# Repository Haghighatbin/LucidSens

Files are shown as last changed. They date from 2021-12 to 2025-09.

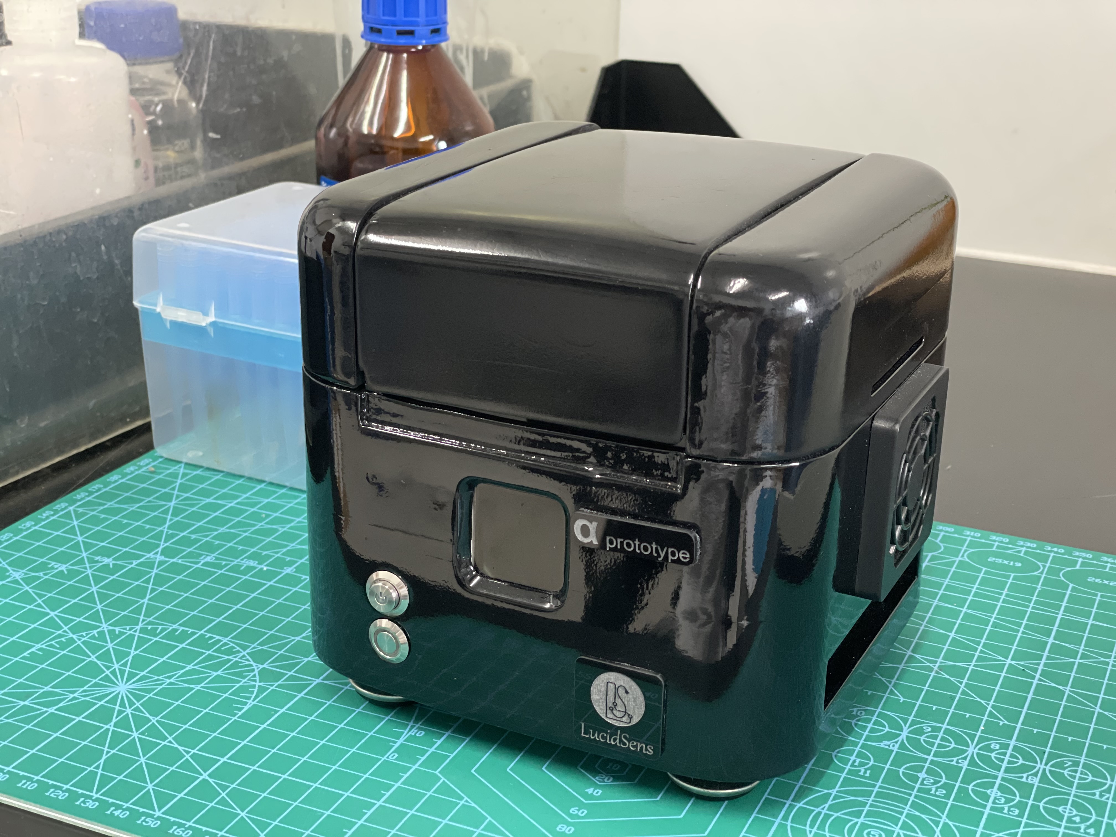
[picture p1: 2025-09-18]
Images/IMG_0355.jpg

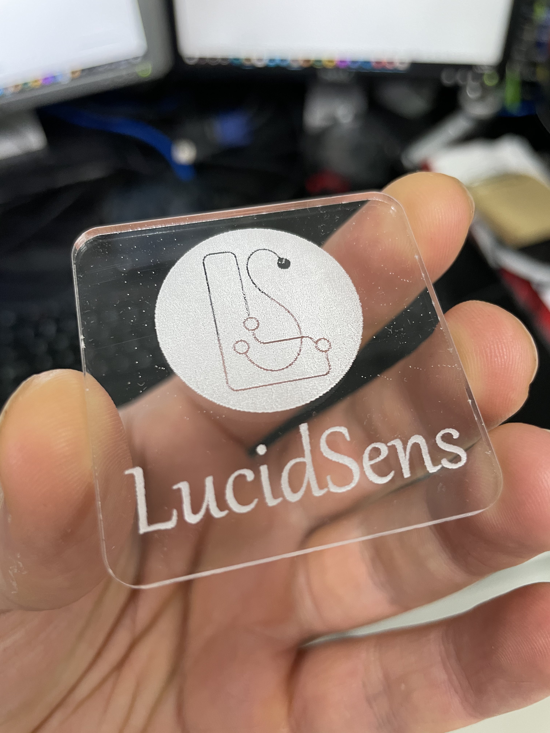
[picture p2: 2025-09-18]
Images/IMG_9384.jpg

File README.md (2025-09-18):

# LucidSens

<b>A device for electrochemiluminescence (ECL)-based measurements</b><br /><br />

<p align='justify'>
  There is a common agreement that the most indicative clinical procedure for rapid and early diagnosis of diseases is to monitor the concentration of specific biomarkers in the patient’s analytical sample at the early stages of the incident using point-of-care (POC) technologies. Among the POC sensing devices, luminescence-based sensing methodologies have been a dominant trend in clinical procedures mostly owing to their tremendously high sensitivity, specificity and rapidity in the analysis of multiplex analytical samples. However, achieving high photosensitivity and versatility to process multiple samples in luminescence-based POC devices commonly come at a cost of compromising the affordability aspect of such sensing devices. <br /><br />To address the gap, <b>LucidSens</b>, a cost-effective luminescence-based POC sensing device is developed for highly sensitive and precise determination of electrochemiluminescence (ECL) and chemiluminescence (CL)-based biological samples. While designed to be portable and cost-efficient, the device provides the versatility of operating in two operational modes: <b>incubation</b> and <b>detection</b> modes. In the incubation mode, the integrity of the process is validated and assured by a PID (proportional, integral, derivative) algorithm with a temperature-sensing feedback loop controlling the implemented Peltier heating/cooling module. In the detection mode, the system is capable of collecting ECL/CL signals of up to 18 analytical samples utilizing an implemented silicon-photomultiplier (SiPM) biased by a miniaturized onboard high-voltage power supply and built-in pseudo-potentiostat modules. The portable architecture of the device as well as remarkable photosensitivity, cost-efficiency and convenient operational instruction may propose the current platform as a versatile analytical template to be adapted for a wide range of ECL/CL-based clinical and bio-analytical determinations.</p><br />
  
Designed and developed by <b><aminhb@tutanota.com></b>

# Firmware
The firmware has been written in Micropython (Loboris port ESP32_LoBo_v3.2.24) based on Espressif ESP32-WROVER-B/I modules with 4MB external SPI flash and 8MB PSRAM.<br />
https://github.com/Haghighatbin/LucidSens/tree/master/Firmware

# Software
Created by: PyQt5 and UI code generator 5.15.4 - sourcefile was written in Python 3.5<br />
https://github.com/Haghighatbin/LucidSens/tree/master/Software   <br />
[Screenshot]
LucidSens_GUI

# PCB Layout and Schematics
https://github.com/Haghighatbin/LucidSens/tree/master/PCB_Schematics_Layouts
LucidSens_2 01v

# CAD files
https://github.com/Haghighatbin/LucidSens/tree/master/CADs

# 3D View
https://user-images.githubusercontent.com/10771949/146338794-2b45d992-ebb1-41cf-bab1-338458c2112e.mp4

# Blueprint 
Blueprint

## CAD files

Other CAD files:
CADs/LinearSlider_0.skp
CADs/LucidSens_01_Blower_REV2.skp
CADs/LucidSens_01_Body_REV2.skp
CADs/LucidSens_01_Body_REV3.skp
CADs/LucidSens_01_Body_REV4.skp
CADs/LucidSens_01_Bracket_REV1.skp
CADs/LucidSens_01_Casquette_REV2.skp
CADs/LucidSens_01_Lid_95.4_REV2.skp
CADs/LucidSens_01_SampleHolder_REV5_51.8.skp
CADs/LucidSens_01_SampleHolder_REV7.skp
CADs/LucidSens_01_TEMPFLOP.skp
CADs/LucidSens_01_Tables.skp
CADs/LucidSens_01_Tables2.skp
CADs/LucidSens_01_Tables2_Interupter.skp
CADs/LucidSens_01_Tables2_SiPM.skp
CADs/LucidSens_beta_BlowerOutlet_BentTube_lefter_twisted_101121.skp
CADs/LucidSens_beta_EJack_TwistedBentBlowerOutlet_MergedSheath_SliderBackHold_301021.skp
CADs/LucidSens_beta_ELever_301021.skp
CADs/LucidSens_beta_ElectrodeJack_SiPMmount_21221.skp
CADs/LucidSens_beta_ElectrodeJack_SiPMmount_301021.skp
CADs/LucidSens_beta_Frontflop_0.skp
CADs/LucidSens_beta_MagneticPogos_301021.skp
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

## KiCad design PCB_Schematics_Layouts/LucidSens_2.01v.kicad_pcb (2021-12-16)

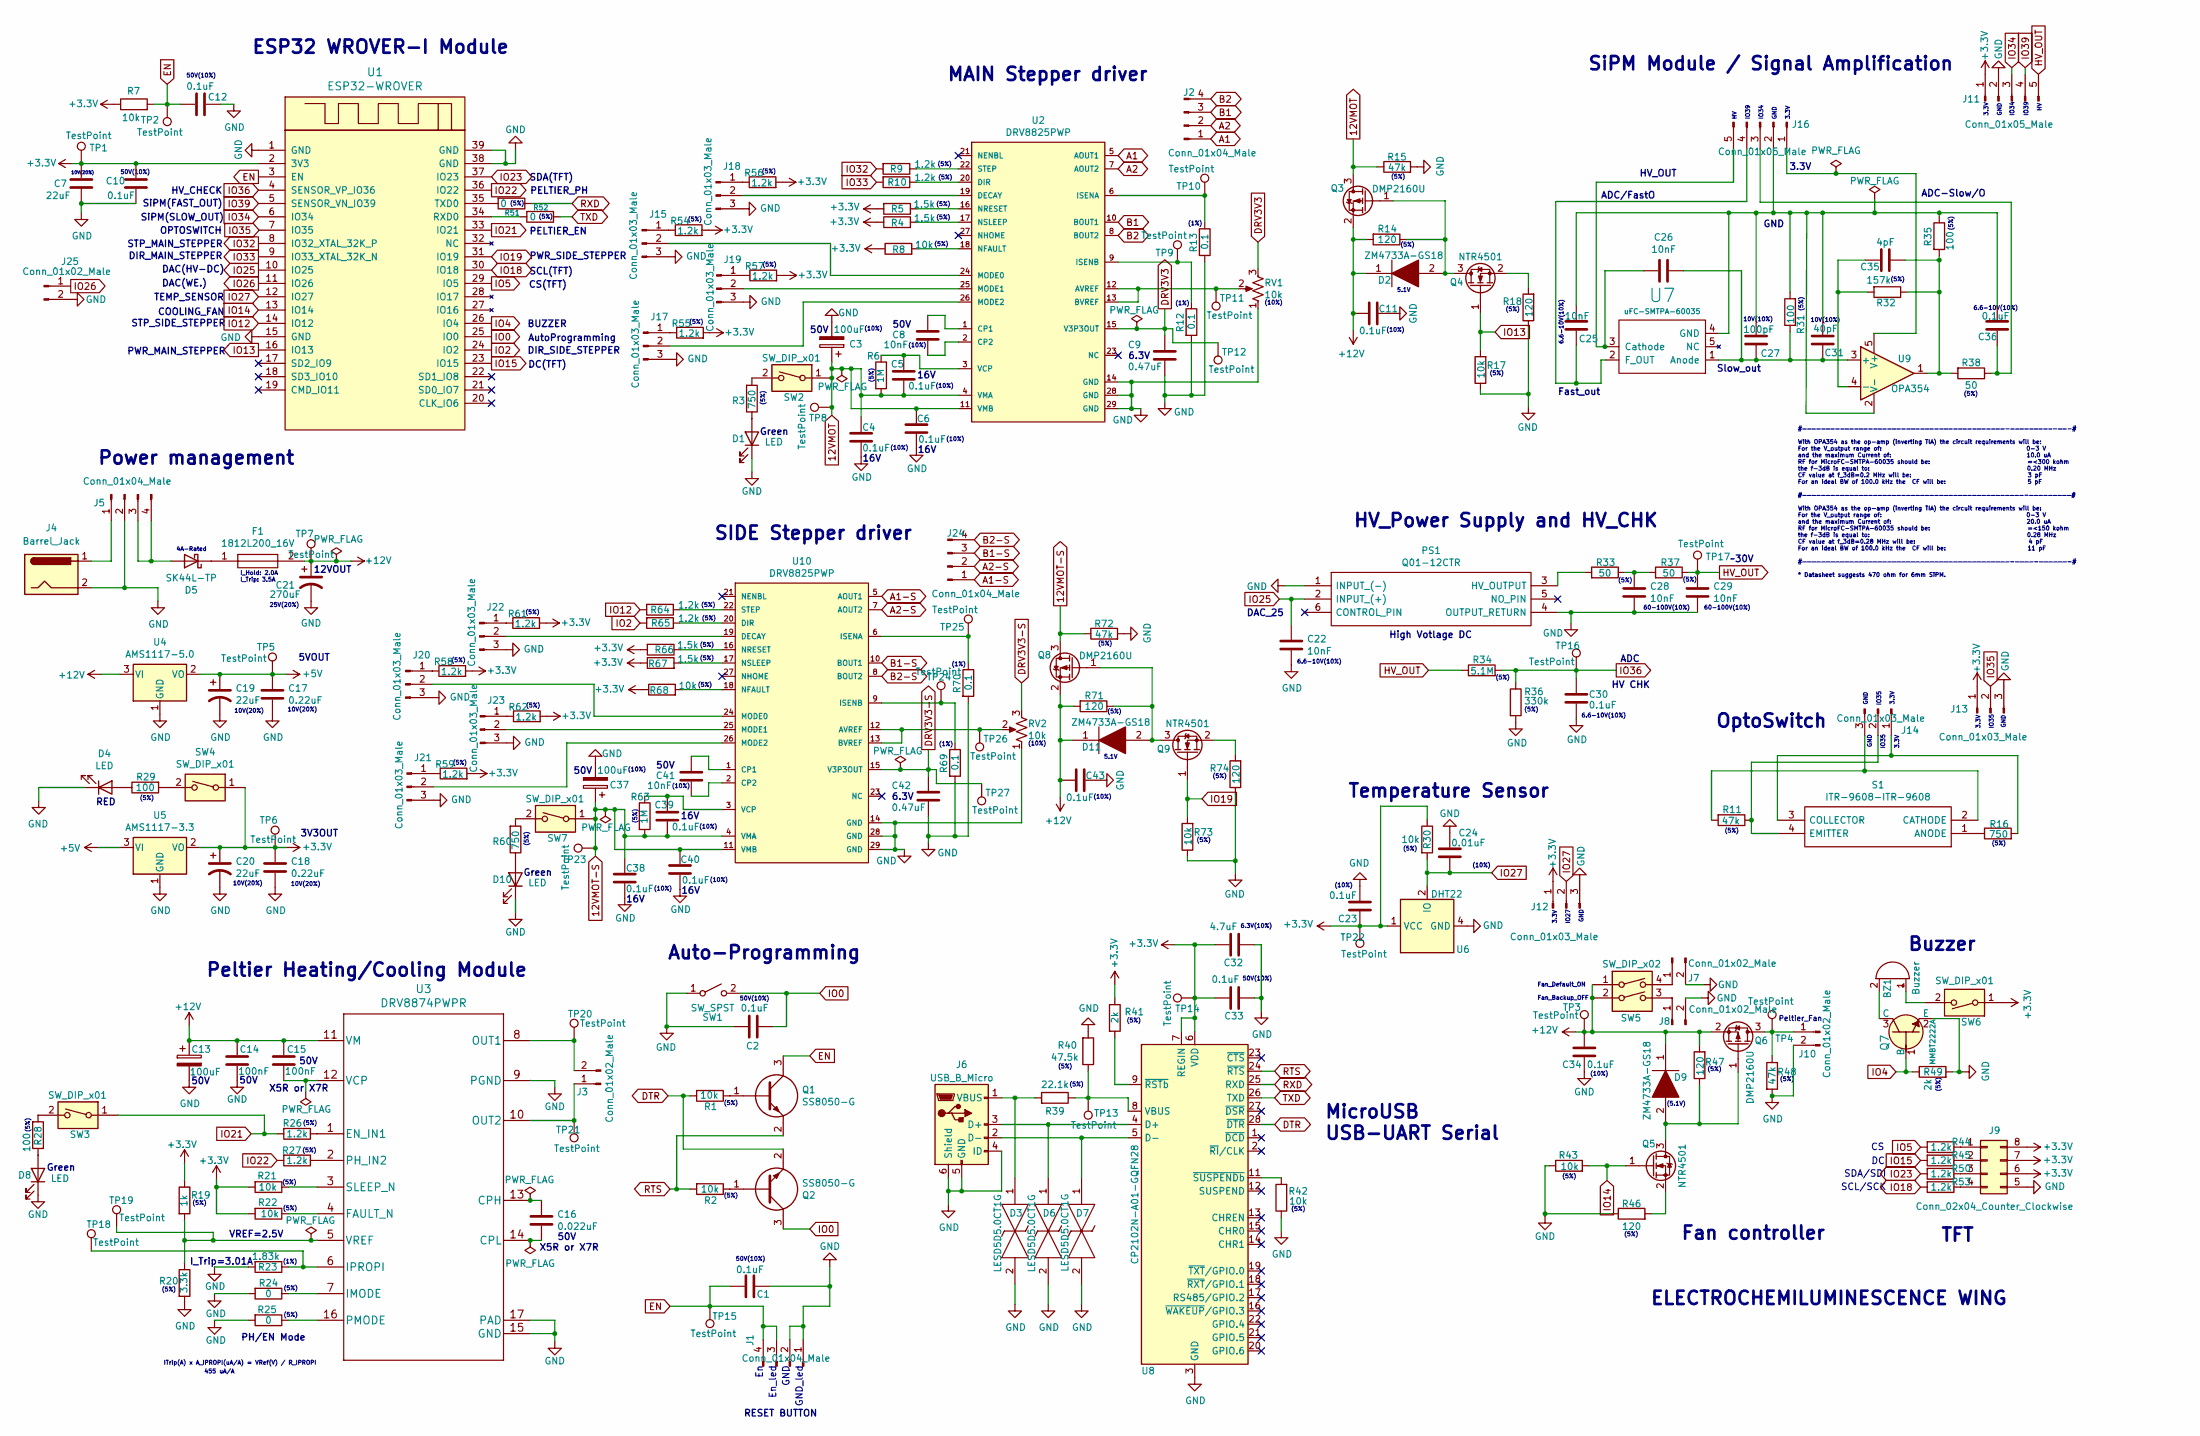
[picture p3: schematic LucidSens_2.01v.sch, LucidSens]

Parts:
BZ1: Buzzer; Buzzer_12x9.5RM7.6
C1, C2, C4, C5, C6, C10, C11, C12, C23, C30, C33, C34, C36, C38, C39, C40, C43: 0.1uF; C_0805_2012Metric_Pad1.18x1.45mm_HandSolder
C3, C13, C37: 100uF; CAPAE660X800N
C7: 22uF; C_0805_2012Metric_Pad1.18x1.45mm_HandSolder
C8, C22, C25, C26, C28, C29, C41: 10nF; C_0805_2012Metric_Pad1.18x1.45mm_HandSolder
C9, C42: 0.47uF; C_0805_2012Metric_Pad1.18x1.45mm_HandSolder
C14, C15: 100nF; C_0805_2012Metric_Pad1.18x1.45mm_HandSolder
C16: 0.022uF; C_0805_2012Metric_Pad1.18x1.45mm_HandSolder
C17, C18: 0.22uF; C_0805_2012Metric_Pad1.18x1.45mm_HandSolder
C19, C20: 22uF; CAPAE530X610N
C21: 270uF; CAPAE830X1050N
C24: 0.01uF; C_0805_2012Metric_Pad1.18x1.45mm_HandSolder
C27: 100pF; C_0805_2012Metric_Pad1.18x1.45mm_HandSolder
C31: 40pF; C_0805_2012Metric_Pad1.18x1.45mm_HandSolder
C32: 4.7uF; C_0805_2012Metric_Pad1.18x1.45mm_HandSolder
C35: 4pF; C_0805_2012Metric_Pad1.18x1.45mm_HandSolder
D1, D4, D8, D10: LED; LED_0805_2012Metric
D2, D9, D11: ZM4733A-GS18; MELF_DO-213AB; Manufacturer_Part_Number ZM4733A-GS18; Mouser Part Number 625-ZM4733A-GS18
D3, D6, D7: LESD5D5.0CT1G; LESD5D50CT1G; Manufacturer_Part_Number LESD5D5.0CT1G
D5: SK44L-TP; D_SMC
F1: 1812L200_16V; FUSC4632X180N; Manufacturer_Part_Number 1812L150/24MR; Mouser Part Number 576-1812L150/24MR
J1, J2, J5, J24: Conn_01x04_Male; PhoenixContact_MSTBVA_2,5_4-G-5,08_1x04_P5.08mm_Vertical
J3: Conn_01x02_Male; TerminalBlock_Phoenix_MKDS-1,5-2-5.08_1x02_P5.08mm_Horizont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
J4: Barrel_Jack; BarrelJack_CUI_PJ-063AH_Horizontal
J6: USB_B_Micro; USB_Micro-B_Molex_47346-0001
J7, J8, J10, J25: Conn_01x02_Male; JST_EH_B2B-EH-A_1x02_P2.50mm_Vertical
J9: Conn_02x04_Counter_Clockwise; JST_PHD_B8B-PHDSS_2x04_P2.00mm_Vertical
J11, J16: Conn_01x05_Male; JST_EH_B5B-EH-A_1x05_P2.50mm_Vertical
J12, J13, J14: Conn_01x03_Male; JST_EH_B3B-EH-A_1x03_P2.50mm_Vertical
J15, J17, J18, J19, J20, J21, J22, J23: Conn_01x03_Male; PinHeader_1x03_P2.54mm_Vertical
PS1: Q01-12CTR; Q0112CTR; Manufacturer_Part_Number Q01-12CTR
Q1, Q2: SS8050-G; SOT95P240X115-3N; Manufacturer_Part_Number SS8050-G; Mouser Part Number 750-SS8050-G
Q3, Q6, Q8: DMP2160U; SOT-23
Q4, Q5, Q9: NTR4501; SOT-23
Q7: MMBT2222A; SOT95P240X120-3N; MPN MMBT2222A-7-F; Digi-Key_PN MMBT2222A-FDICT-ND
R1, R2, R7, R8, R17, R21, R22, R30, R42, R43, R68, R73: 10k; R_0805_2012Metric_Pad1.20x1.40mm_HandSolder
R3, R16, R60: 750; R_0805_2012Metric_Pad1.20x1.40mm_HandSolder
R4, R5, R66, R67: 1.5k; R_0805_2012Metric_Pad1.20x1.40mm_HandSolder
R6, R63: 1M; R_0805_2012Metric_Pad1.20x1.40mm_HandSolder
R9, R10, R26, R27, R44, R45, R50, R53, R54, R55, R56, R57, R58, R59, R61, R62, R64, R65: 1.2k; R_0805_2012Metric_Pad1.20x1.40mm_HandSolder
R11, R15, R48, R72: 47k; R_0805_2012Metric_Pad1.20x1.40mm_HandSolder
R12, R13, R69, R70: 0.1; R_0805_2012Metric_Pad1.20x1.40mm_HandSolder
R14, R18, R46, R47, R71, R74: 120; R_0805_2012Metric_Pad1.20x1.40mm_HandSolder
R19: 1k; R_0805_2012Metric_Pad1.20x1.40mm_HandSolder
R20: 3.3k; R_0805_2012Metric_Pad1.20x1.40mm_HandSolder
R23: 1.83k; R_0805_2012Metric_Pad1.20x1.40mm_HandSolder
R24, R25, R51, R52: 0; R_0805_2012Metric_Pad1.20x1.40mm_HandSolder
R28, R29, R31, R35: 100; R_0805_2012Metric_Pad1.20x1.40mm_HandSolder
R32: 157k; R_0805_2012Metric_Pad1.20x1.40mm_HandSolder
R33, R37, R38: 50; R_0805_2012Metric_Pad1.20x1.40mm_HandSolder
R34: 5.1M; R_0805_2012Metric_Pad1.20x1.40mm_HandSolder
R36: 330k; R_0805_2012Metric_Pad1.20x1.40mm_HandSolder
R39: 22.1k; R_0805_2012Metric_Pad1.20x1.40mm_HandSolder
R40: 47.5k; R_0805_2012Metric_Pad1.20x1.40mm_HandSolder
R41, R49: 2k; R_0805_2012Metric_Pad1.20x1.40mm_HandSolder
RV1, RV2: 10k; SM43TW103
S1: ITR-9608-ITR-9608; ITR9608; Manufacturer_Part_Number ITR-9608; Mouser Part Number 638-ITR9608
SW1: SW_SPST; SW_SPST_TL3342
SW2, SW3, SW4, SW6, SW7: SW_DIP_x01; SW_DIP_SPSTx01_Slide_Omron_A6S-110x_W8.9mm_P2.54mm
SW5: SW_DIP_x02; SW_DIP_SPSTx02_Slide_Omron_A6S-210x_W8.9mm_P2.54mm
TP1, TP2, TP3, TP4, TP5, TP6, TP7, TP8, TP9, TP10, TP11, TP12, TP13, TP14, TP15, TP16, TP17, TP18, TP19, TP20, TP21, TP22, TP23, TP24, TP25, TP26, TP27: TestPoint; TestPoint_Pad_D1.5mm
U1: ESP32-WROVER
U2, U10: DRV8825PWP; Texas_Instruments-DRV8825PWP-Level_A; Tolerance 20%; Voltage Rating 100 V
U3: DRV8874PWPR
U4: AMS1117-5.0; SOT-223-3_TabPin2
U5: AMS1117-3.3; SOT-223-3_TabPin2
U6: DHT22; Aosong_DHT11_5.5x12.0_P2.54mm
U7: uFC-SMTPA-60035; uFC-SMTPA-6mm
U8: CP2102N-A01-GQFN28; QFN-28-1EP_5x5mm_P0.5mm_EP3.35x3.35mm
U9: OPA354; SOT-23-5

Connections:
12VMOT: C3.1, C4.1, C5.2, C6.1, Q3.3 (D), R6.2, R15.1, SW2.1, TP8.1, U2.4 (VMA), U2.11 (VMB)
12VMOT-S: C37.1, C38.1, C39.2, C40.1, Q8.3 (D), R63.2, R72.1, SW7.1, TP23.1, U10.4 (VMA), U10.11 (VMB)
+3V3: C7.2, C10.1, C18.1, C20.1, C23.1, C32.1, C33.1, J9.6, J9.7, J9.8, J11.1, J12.1, J13.1, R4.1, R5.2, R7.1, R8.1, R19.1, R21.2, R22.2, R30.1, R41.1, R54.2, R55.2, R56.2, R57.2, R58.2, R59.2, R61.2, R62.2, R66.2, R67.1, R68.1, SW4.1, SW6.1, TP1.1, TP6.1, TP14.1, TP22.1, U1.2 (3V3), U5.2 (VO), U8.6 (VDD), U8.7 (REGIN)
+5V: C17.1, C19.1, TP5.1, U4.2 (VO), U5.3 (VI)
+12V: C11.1, C13.1, C14.1, C15.1, C21.1, C34.1, C43.1, D2.1, D9.1, D11.1, F1.2, Q3.2 (S), Q6.2 (S), Q8.2 (S), R14.2, R47.2, R71.2, SW5.1, SW5.2, TP3.1, TP7.1, U3.11 (VM), U4.3 (VI)
A1: J2.1, U2.5 (AOUT1)
A1-S: J24.1, U10.5 (AOUT1)
A2: J2.2, U2.7 (AOUT2)
A2-S: J24.2, U10.7 (AOUT2)
B1: J2.3, U2.10 (BOUT1)
B1-S: J24.3, U10.10 (BOUT1)
B2: J2.4, U2.8 (BOUT2)
B2-S: J24.4, U10.8 (BOUT2)
DRV3V3: C9.1, RV1.3, TP12.1, U2.15 (V3P3OUT)
DRV3V3-S: C42.1, RV2.3, TP27.1, U10.15 (V3P3OUT)
DTR: Q2.2, R1.2, U8.28 (~DTR)
EN: C1.1, C12.1, J1.3, J1.4, Q1.3, R7.2, TP2.1, TP15.1, U1.3 (EN)
GND: C1.2, C2.1, C3.2, C4.2, C6.2, C7.1, C9.2, C10.2, C11.2, C12.2, C13.2, C14.2, C17.2, C18.2, C19.2, C20.2, C21.2, C22.2, C23.2, C24.2, C28.2, C29.2, C30.2, C32.2, C33.2, C34.2, C37.2, C38.2, C40.2, C42.2, C43.2, D1.1 (K), D3.2, D4.1 (K), D6.2, D7.2, D8.1 (K), D10.1 (K), J1.1, J1.2, J4.2, J5.2, J6.4 (ID), J6.5 (GND), J6.6 (Shield), J7.2, J8.2, J9.5, J10.2, J11.2, J12.3, J13.3, J15.3, J17.3, J18.3, J19.3, J20.3, J21.3, J22.3, J23.3, J25.2, PS1.1 (INPUT_(-)), PS1.4 (OUTPUT_RETURN), Q7.2 (E), R12.2, R13.2, R15.2, R17.1, R18.1, R20.2, R23.2, R24.2, R25.2, R36.2, R40.2, R42.1, R43.1, R46.1, R48.2, R49.2, R69.2, R70.2, R72.2, R73.1, R74.1, RV1.1, RV2.1, SW1.1 (A), U1.1 (GND), U1.15 (GND), U1.38 (GND), U1.39 (GND), U2.14 (GND), U2.28 (GND), U2.29 (GND), U2.~, U3.9 (PGND), U3.15 (GND), U3.17 (PAD), U3.18, U3.19, U3.20, U3.21, U3.22, U3.23, U3.24, U3.25, U3.26, U3.27, U3.28, U3.29, U3.30, U3.31, U3.32, U4.1 (GND), U5.1 (GND), U6.4 (GND), U8.3 (GND), U8.29 (GND), U10.14 (GND), U10.28 (GND), U10.29 (GND), U10.~
HV_OUT: C29.1, J11.5, R34.1, R37.1, TP17.1
IO0: C2.2, Q2.3, SW1.2 (B), U1.25 (IO0)
IO2: R65.2, U1.24 (IO2)
IO4: Q7.1 (B), R49.1, U1.26 (IO4)
IO5: R44.2, U1.29 (IO5)
IO12: R64.2, U1.14 (IO12)
IO13: Q4.1 (G), R17.2, U1.16 (IO13)
IO14: Q5.1 (G), R43.2, U1.13 (IO14)
IO15: R45.2, U1.23 (IO15)
IO18: R53.2, U1.30 (IO18)
IO19: Q9.1 (G), R73.2, U1.31 (IO19)
IO21: R26.2, SW3.1, U1.33 (IO21)
IO22: R27.2, U1.36 (IO22)
IO23: R50.2, U1.37 (IO23)
IO25: C22.1, PS1.2 (INPUT_(+)), U1.10 (IO25)
IO26: J25.1, U1.11 (IO26)
IO27: C24.1, J12.2, R30.2, U1.12 (IO27), U6.2 (IO)
IO32: R9.2, U1.8 (IO32_XTAL_32K_P)
IO33: R10.2, U1.9 (IO33_XTAL_32K_N)
IO34: J11.3, U1.6 (IO34)
IO35: J13.2, U1.7 (IO35)
IO36: C30.1, R34.2, R36.1, TP16.1, U1.4 (SENSOR_VP_IO36)
IO39: J11.4, U1.5 (SENSOR_VN_IO39)
unnamed: BZ1.1 (-), SW6.2
unnamed: BZ1.2 (+), Q7.3 (C)
unnamed: C5.1, R6.1, U2.3 (VCP)
unnamed: C8.1, U2.1 (CP1)
unnamed: C8.2, U2.2 (CP2)
unnamed: C15.2, U3.12 (VCP)
unnamed: C16.1, U3.13 (CPH)
unnamed: C16.2, U3.14 (CPL)
unnamed: C25.1, J16.4, U7.2 (F_OUT)
unnamed: C25.2, C27.2, C31.1, C36.2, J16.2, R31.2, R35.1, U7.4 (GND), U9.2 (V-)
unnamed: C26.1, C27.1, C31.2, R31.1, U7.1 (Anode), U9.3 (+)
unnamed: C26.2, J16.5, U7.3 (Cathode)
unnamed: C28.1, R33.1, R37.2
unnamed: C35.1, R32.2, U9.4 (-)
unnamed: C35.2, R32.1, R35.2, R38.2, U9.1
unnamed: C36.1, J16.3, R38.1
unnamed: C39.1, R63.1, U10.3 (VCP)
unnamed: C41.1, U10.1 (CP1)
unnamed: C41.2, U10.2 (CP2)
unnamed: D1.2 (A), R3.1
unnamed: D2.2, Q3.1 (G), Q4.3 (D), R14.1
unnamed: D3.1, J6.1 (VBUS), R39.2
unnamed: D4.2 (A), R29.1
unnamed: D5.1 (K), F1.1
unnamed: D5.2 (A), J5.3, J5.4
unnamed: D6.1, J6.3 (D+), U8.4 (D+)
unnamed: D7.1, J6.2 (D-), U8.5 (D-)
unnamed: D8.2 (A), R28.1
unnamed: D9.2, Q5.3 (D), Q6.1 (G), R47.1
unnamed: D10.2 (A), R60.1
unnamed: D11.2, Q8.1 (G), Q9.3 (D), R71.1
unnamed: J3.1, TP21.1, U3.10 (OUT2)
unnamed: J3.2, TP20.1, U3.8 (OUT1)
unnamed: J4.1, J5.1
unnamed: J7.1, SW5.4
unnamed: J8.1, SW5.3
unnamed: J9.1, R44.1
unnamed: J9.2, R45.1
unnamed: J9.3, R50.1
unnamed: J9.4, R53.1
unnamed: J10.1, Q6.3 (D), R48.1, TP4.1
unnamed: J14.1, R16.2, S1.3 (COLLECTOR)
unnamed: J14.2, R11.1, S1.4 (EMITTER)
unnamed: J14.3, R11.2, S1.2 (CATHODE)
unnamed: J15.1, R54.1
unnamed: J15.2, U2.24 (MODE0)
unnamed: J16.1, U9.5 (V+)
unnamed: J17.1, R55.1
unnamed: J17.2, U2.26 (MODE2)
unnamed: J18.1, R56.1
unnamed: J18.2, U2.19 (DECAY)
unnamed: J19.1, R57.1
unnamed: J19.2, U2.25 (MODE1)
unnamed: J20.1, R58.1
unnamed: J20.2, U10.24 (MODE0)
unnamed: J21.1, R59.1
unnamed: J21.2, U10.26 (MODE2)
unnamed: J22.1, R61.1
unnamed: J22.2, U10.19 (DECAY)
unnamed: J23.1, R62.1
unnamed: J23.2, U10.25 (MODE1)
unnamed: PS1.3 (HV_OUTPUT), R33.2
unnamed: Q1.1, R1.1
unnamed: Q2.1, R2.1
unnamed: Q4.2 (S), R18.2
unnamed: Q5.2 (S), R46.2
unnamed: Q9.2 (S), R74.2
unnamed: R3.2, SW2.2
unnamed: R4.2, U2.17 (NSLEEP)
unnamed: R5.1, U2.16 (NRESET)
unnamed: R8.2, U2.18 (NFAULT)
unnamed: R9.1, U2.22 (STEP)
unnamed: R10.1, U2.20 (DIR)
unnamed: R12.1, TP9.1, U2.9 (ISENB)
unnamed: R13.1, TP10.1, U2.6 (ISENA)
unnamed: R16.1, S1.1 (ANODE)
unnamed: R19.2, R20.1, TP19.1, U3.5 (VREF)
unnamed: R21.1, U3.3 (SLEEP_N)
unnamed: R22.1, U3.4 (FAULT_N)
unnamed: R23.1, TP18.1, U3.6 (IPROPI)
unnamed: R24.1, U3.7 (IMODE)
unnamed: R25.1, U3.16 (PMODE)
unnamed: R26.1, U3.1 (EN_IN1)
unnamed: R27.1, U3.2 (PH_IN2)
unnamed: R28.2, SW3.2
unnamed: R29.2, SW4.2
unnamed: R39.1, R40.1, TP13.1, U8.8 (VBUS)
unnamed: R41.2, U8.9 (~RSTb)
unnamed: R42.2, U8.11 (~SUSPENDb)
unnamed: R51.2, U1.35 (TXD0)
unnamed: R52.2, U1.34 (RXD0)
unnamed: R60.2, SW7.2
unnamed: R64.1, U10.22 (STEP)
unnamed: R65.1, U10.20 (DIR)
unnamed: R66.1, U10.16 (NRESET)
unnamed: R67.2, U10.17 (NSLEEP)
unnamed: R68.2, U10.18 (NFAULT)
unnamed: R69.1, TP24.1, U10.9 (ISENB)
unnamed: R70.1, TP25.1, U10.6 (ISENA)
unnamed: RV1.2, TP11.1, U2.12 (AVREF), U2.13 (BVREF)
unnamed: RV2.2, TP26.1, U10.12 (AVREF), U10.13 (BVREF)
RTS: Q1.2, R2.2, U8.24 (~RTS)
RXD: R51.1, U8.25 (RXD)
TXD: R52.1, U8.26 (TXD)

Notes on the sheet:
ESP32 WROVER-I Module
DAC(HV-DC)
DIR_MAIN_STEPPER
STP_MAIN_STEPPER
OPTOSWITCH
SiPM(SLOW_OUT)
SiPM(FAST_OUT)
HV_CHECK
PWR_MAIN_STEPPER
BUZZER
DC(TFT)
PELTIER_PH
PELTIER_EN
50V(10%)
(5%)
GND
3.3V
IO34
IO39
IO35
10V(20%)
COOLING_FAN
SCL(TFT)
SDA(TFT)
CS(TFT)
AutoProgramming
TEMP_SENSOR
IO27
#———————————————————————————————————————————-—————————-——-# With OPA354 as the op-amp (inverting TIA) the circuit requirements will be: For the V_output range of: 0-3 V and the maximum Current of: 10.0 uA RF for MicroFC-SMTPA-60035 should be: =<300 kohm the f-3dB is equal to: 0.20 MHz CF value at f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
SiPM Module / Signal Amplification
HV_OUT
6.6-10V(10%)
10V(10%)
ADC/FastO
ADC-Slow/O
Fast_out
Slow_out
(10%)
5.1V
(1%)

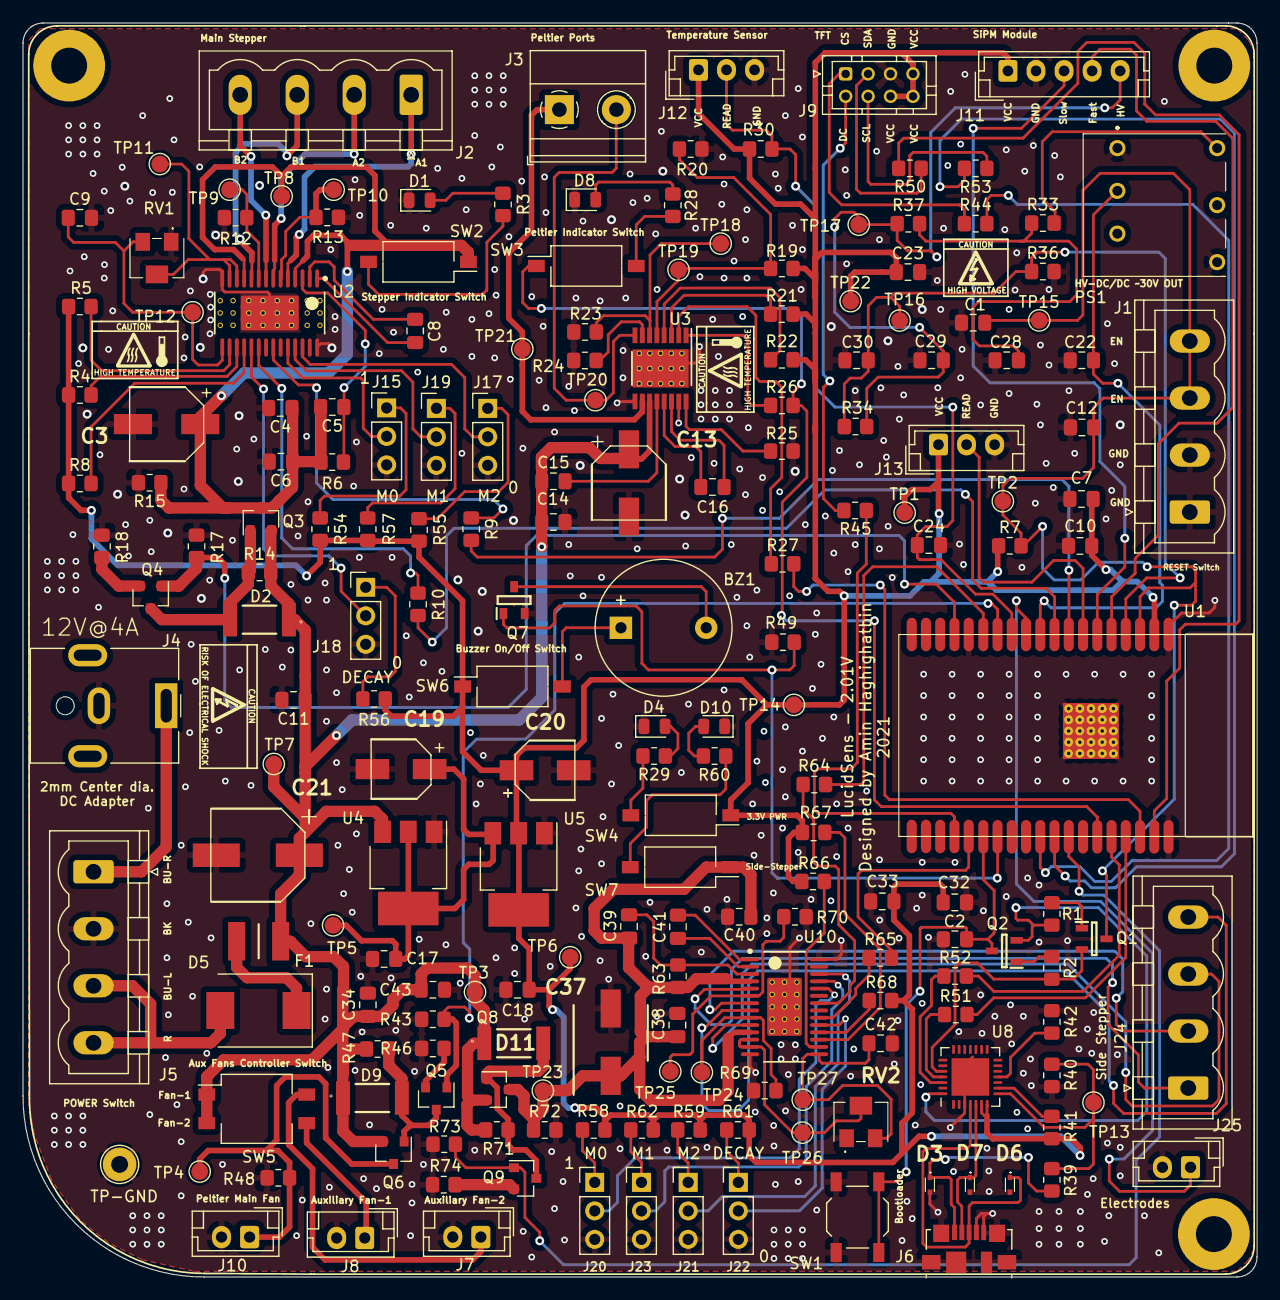
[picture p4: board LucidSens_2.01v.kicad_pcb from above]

Board: 2 copper layers, 110.0 x 111.8 mm, 194 parts (0 on the bottom side), 133 nets.

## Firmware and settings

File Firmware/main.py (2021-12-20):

"""
LucidSens(2021)

This firmware has been written for the LucidSens device based on Micropython (Loboris port ESP32_LoBo_v3.2.24).

Licensed under XXX:

Firmware: https://github.com/haghighatbin/LucidSens_Firmware.git
GUI: https://github.com/haghighatbin/LucidSens_GUI.git

aminhb@tutanota.com
"""
# pylint: disable=no-name-in-module
# pylint: disable=no-member
# pylint: disable=eval-used

import sys, os, _thread, gc
from array import array
from display import TFT
from network import WLAN, STA_IF
from machine import Pin, ADC, DAC, PWM, RTC, DHT, stdin_get, stdout_put
from utime import sleep, strftime, localtime
import usocket as socket
import ujson as json
from upysh import *

# Color Codes
GREEN = '\033[92m'
RED = '\033[91m'
CYAN = '\033[96m'
PINK  = '\033[95m'
YELLOW = '\033[93m'
WHITE = '\033[97m'

# ST7735_INVOFF = const(0x20)
# ST7735_INVON = const(0x21)

for p in [5, 13, 14, 15, 21]:
    Pin(p, Pin.OUT, value=0)
print('pins 5, 13, 14, 15, 21 were pulled down.' + WHITE)
print(GREEN + 'THREAD stack_size is: {}'.format(_thread.stack_size(4 * 4096)))
gc.enable()

class MemSweep:
    def gc_thrd():
        _thread.allowsuspend(True)
        while True:
            ntf = _thread.getnotification()
            if ntf == _thread.EXIT:
                return
            elif ntf == _thread.SUSPEND:
                for thrd in _thread.list(False):
                    if thrd[2] == 'gc_thrd':
                        _thread.suspend(thrd[0])
                while _thread.wait() != _thread.RESUME:
                    pass

            gc.threshold(gc.mem_free() // 4 + gc.mem_alloc())
            if gc.mem_free() < gc.threshold():
                gc.collect()
            sleep(10)

class KillThreads:
    def __repr__(self):
        return _thread.notify(0, _thread.EXIT)
    def __call__(self):
        return self.__repr__()

class ClearScreen:
    def __repr__(self):
        return "\x1b[2J\x1b[H"
    def __call__(self):
        return self.__repr__()

class TemperatureSensor:
    # pylint: disable=too-few-public-methods
    def __init__(self):
        self.dht = DHT(Pin(27), DHT.DHT2X)
        self.temperature = str(25) # some random initial values, in case the sensor's disconnected
        self.humidity = str(55)

    def read(self):
        sensor = self.dht.read()
        if sensor[0]:
            self.temperature, self.humidity = sensor[1], sensor[2]
            return [self.temperature, self.humidity]
        else:
            return False

class CommandHandler:
    """Handles the commands received from the GUI and calls the appropriate modules."""
    def __init__(self):
        self.clear = ClearScreen()

    def test_mod(self, iterations):
        """Checks the validity of USB-UART connection. Generates a list of an astroid's coordinates as a test sample."""
        n = iterations
        response = ({'header': 'test'})
        response.update({'body': [[(i, 0), (0, abs(abs(i) - n)), (0, -(abs(abs(i) - n)))] for i in range(-n, n + 1)]})
        jsnd_response = json.dumps(response)
        return jsnd_response

    def operator(self, command):
        """Processes the commands received and calls the required modules."""
        if command['header'] == 'test':
            astroid = self.test_mod(command['body']['it'])
            with open('resp.txt', 'w') as resp:
                resp.write(astroid)
            with open('resp.txt', 'r') as r:
                for line in r:
                    return line

        elif command['header'] == 'incubation':
            stpr = SamplingModule()
            _thread.start_new_thread('incubation_thrd', stpr.incubation_thrd, (300, 50, 0,
                float(command['body']['it']),
                float(command['body']['ip']),
                str(command['body']['bf'])))
            response = ({'header': 'incubation'})
            response.update(
                {'body':'Incubation has been initialised.\n\nNote: you may cancel the incubation by clicking on the Stop button.'})
            return json.dumps(response)

        elif command['header'] == 'sampling':
            stpr = SamplingModule()
            # This code-block in thread halts the CPU!
            # _thread.start_new_thread(...)
            stpr.sampling_thrd(0, 1,
                float(command['body']['e']),      # applied potential
                float(command['body']['sqt']),    # quiet time
                int(command['body']['sn']),       # number of samples
                float(command['body']['st']),     # total sampling time spent on each sample
                float(command['body']['si']),     # sampling intervals
                int(command['body']['r2avg']),    # raw-to-average
                str(command['body']['pmr']),      # photodetection mode
                float(command['body']['pv']))     # high voltage value

        elif command['header'] == 'kill':
            for thrd in _thread.list(False):
                if thrd[2] == 'incubation_thrd':
                    _thread.notify(thrd[0], _thread.EXIT)
            response = ({'header': 'kill'})
            response.update({'body': 'Incubation has been canceled.'})
            return json.dumps(response)

        elif command['header'] == 'wifi':
            wfcreds = "ip = {}\nport = {}\nsubnet = {}\ngateway = {}\ndns = {}\nessid = {}\npassword = {}".format(
                command['body']['ip'],
                command['body']['port'],
                command['body']['subnet'],
                command['body']['gateway'],
                command['body']['dns'],
                command['body']['essid'],
                command['body']['password'])
            response = ({'header': 'wifi'})
            response.update({'body': 'Wifi credentials were updated on the LucidSens. Please restart the device and re-establish your connection.'})
            with open('wfcreds.txt', 'w') as f:
                f.write(wfcreds)
            return json.dumps(response)
        else:
            pass

class DetectionModule:
    """Handles analog readings on pin (36: assigned to HV) and pins (34, 39: assigned to SiPM).
    Pin 25 was assigned to DAC
    """
    def __init__(self, adc_pin, dac1_pin=25, voltage=20):
        self.adc = ADC(adc_pin)
        if adc_pin == 36:
            self.mode = 'hv'
        elif adc_pin in [34, 39]:
            self.mode = 'sipm'
        else:
            raise RuntimeError('Invalid pin definition or wrong call.')
        self.voltage = voltage
        self.adc.atten(ADC.ATTN_11DB)
        self.dac1 = DAC(dac1_pin)

    def sampler(self, acquisition=3, intervals=0.1, raw_to_avrg=10):
        """
        acquisition: ADC total read-time in seconds
        intervals: sampling intervals in seconds
        raw_to_avrg: number of raw samples to be collected and averaged between the two intervals
        returns an array[list] of the ADC read
        """
        def dac1_calibration(val):
            """DAC calibration module for a linear voltage-to-response read."""
            return int((val + 5.15) / 0.39)

        def adc_calibration(data):
            """ADC calibration module for a linear signal-to-voltage read."""
            if self.mode == 'hv':
                return (data + 176.3)/79.3 # calibrated on 8052021
            elif self.mode == 'sipm':
                return (data + 168.6)/1288.2
            else:
                raise RuntimeError('Invalid pin definition or wrong call.')

        frq = int(raw_to_avrg / intervals)
        datapoint = array('H', raw_to_avrg)
        true_set = array('d')
        calib_set = array('d')

        self.dac1.write(dac1_calibration(self.voltage))

        for _ in range(int(acquisition/intervals)):
            self.adc.collect(freq=frq, data=datapoint)
            while True:
                try:
                    if not self.adc.progress()[0]:
                        true_val = self.adc.collected()[2]
                        # returns the average, 0 -> Min, 1-> Max, 3 -> rms
                        calib_val = adc_calibration(self.adc.collected()[2])
                        true_set.append(true_val)
                        calib_set.append(calib_val)
                        # print("True_point: {} ----- Caliberated_point: {}".format(true_val, calib_val))
                        break
                except KeyboardInterrupt:
                    self.adc.deinit()
                    return
                except Exception as e:
                    self.adc.deinit()
                    print(e)
                    return "deinitialised the ADC, pins were released, exiting."
        # print('true val: {}'.format(round(sum(true_set)/len(true_set),1)))
        # print('calib val: {}'.format(round(sum(calib_set)/len(calib_set),2)))

        # returning the list of calibrated acquired values
        return calib_set

    def deinit(self):
        self.adc.deinit()
        self.dac1.write(0)
        self.dac1.deinit()

class EJack:
    # pylint: disable=too-many-instance-attributes
    """ESP32 (PWM-based) Micropython class for DRV8825 stepper-motor driver.
    pylint: disable=too-many-instance-attributes
    """
    def __init__(self, pwr_pin=19, dir_pin=2, step_pin=12):
        """Initialization of the stepper driver associated with the side-stepper
        Side_Stepper involved pins: 19, 2, 12
        """
        self.pwr = Pin(pwr_pin, Pin.INOUT, value=0)
        self.dir = Pin(dir_pin, Pin.INOUT, value=0)
        self.stepper = Pin(step_pin, Pin.OUT, value=0)
        self.spr = 200  # 200 Steps per revolution: 360 / 1.8

    def lift_up(self, rounds=500, delay=0.002):
        """EJack lifts up."""
        self.dir.value(0)
        self.pwr.value(1)

        try:
            for _ in range(rounds):
                self.stepper.value(1)
                sleep(delay)
                self.stepper.value(0)
            self.pwr.value(0)
        except KeyboardInterrupt:
            self.pwr.value(0)
            return 'aborted!'
        except Exception as e:
            print(e)
            self.pwr.value(0)
            return 'something is not right! shutting down.'

    def pull_down(self, rounds=500, delay=0.002):
        """EJack pulls down."""
        self.dir.value(1)
        self.pwr.value(1)
        try:
            for _ in range(rounds):
                self.stepper.value(1)
                sleep(delay)
                self.stepper.value(0)
            self.pwr.value(0)
        except KeyboardInterrupt:
            self.pwr.value(0)
            return 'aborted!'
        except Exception as e:
            print(e)
            self.pwr.value(0)
            return 'something is not right! shutting down.'

class EChem:
    # pylint: disable=too-many-instance-attributes
    """Initialises DAC2 and controls the potentials at the working electrode pin.
    """
    def __init__(self, dac2_pin=26):
        self.dac2 = DAC(dac2_pin)

    def dac2_calibration(self, val):
        """DAC2 calibration module for a linear voltage-to-response read."""
        return int((val - 0.087) / 0.012)

    def applied_potential(self, e):
        self.dac2.write(self.dac2_calibration(e))

    def release(self):
        self.dac2.write(0)

    def deinit(self):
        self.dac2.write(0)
        self.dac2.deinit()

class SamplingModule:
    # pylint: disable=too-many-instance-attributes
    """ESP32 (PWM-based) Micropython class for DRV8825 stepper-motor driver.
    pylint: disable=too-many-instance-attributes
    """
    def __init__(self, pwr_pin=13, dir_pin=33, step_pin=32, intrptr_pin=35):
        """Initialization of the stepper driver and the peltier module."""
        self.pwr = Pin(pwr_pin, Pin.INOUT, value=0)
        self.dir = Pin(dir_pin, Pin.INOUT, value=0)
        self.intrptr = Pin(intrptr_pin, Pin.IN)
        self.step_pin = step_pin
        self.spr = 200
        self.delay = 0.01
        self._current_temp = TemperatureSensor()
        self.current_temp = float()
        self.target_temp = float()
        self.p_BF = Pin(14, Pin.INOUT, value=0)
        self.p_EN = Pin(21, Pin.INOUT, value=0)
        self.p_PH = Pin(22, Pin.INOUT, value=0)
        self.timer = 0
        self.blower = 'Off'
        self.collected_data = []
        self.ejack = EJack()
        self.echem = EChem()

    def incubation_thrd(self, freq=300, duty=50, direction=0, duration=1, target_temp=37, blower='On'):
        """Motor rotates for [duration]minutes."""
        _thread.allowsuspend(True)
        stepper = PWM(self.step_pin)
        duration = duration * 60
        self.timer = duration
        self.blower = blower
        def ramp_gen(freq):
            _a, _b, _base = 1, 7, 100
            return [int(freq * 1/(1+2**(_a*(x-_b))) * 1/(1+2**(-_a*(x+_b)))) + _base for x in range(-12,13)]

        ramp = ramp_gen(freq)
        self.target_temp = target_temp
        while True:
            notif = _thread.getnotification()
            if notif == _thread.EXIT:
                self.p_EN.value(0)
                self.p_BF.value(0)
                self.interrupter()
                return

            try:
                self.current_temp = self._current_temp.read()
                sleep(1)
                if self.current_temp is not False:
                    tft.ambient_temp_sensor()
                    if self.current_temp[0] < int(self.target_temp - 1):
                        tft.temp_status('rising')
                        if self.pwr.value():
                            self.pwr.value(0)
                            sleep(1)

                        if self.blower == 'On':
                            if not self.p_BF.value():
                                self.p_BF.value(1)
                                sleep(1)

                        if not self.p_EN.value():
                            self.p_EN.value(1)

                        if self.p_PH.value():
                            self.p_PH.value(0)
                        sleep(15)

                    elif self.current_temp[0] > int(self.target_temp + 1):
                        tft.temp_status('falling')
                        if self.pwr.value():
                            self.pwr.value(0)
                            sleep(1)

                        if self.blower == 'On':
                            if not self.p_BF.value():
                                self.p_BF.value(1)

                        for pin in [self.p_EN, self.p_PH]:
                            if not pin.value():
                                pin.value(1)
                        sleep(15)

                    else:
                        for pin in [self.p_EN, self.p_BF, self.p_PH]:
                            pin.value(0)
                        sleep(3)
                        tft.temp_status('idle')
                        self.dir.value(direction if direction in [0, 1] else 0)
                        stepper.duty(duty)
                        self.pwr.value(1)
                        for idx, frequency in enumerate(ramp):
                            # print(idx, frequency)
                            if int(self.target_temp - 1) <= self.current_temp[0] <= int(self.target_temp + 1):
                                stepper.freq(frequency)
                                sleeping_time = round((duration / sum(ramp)) * frequency, 3)
                                # print('@Frequency: {}Hz --- Duration: {}s'.format(frequency, sleeping_time))
                                sleep(sleeping_time)
                                self.timer -= sleeping_time
                                self.current_temp = self._current_temp.read()
                                # print("current temperature: {}".format(self.current_temp[0]))
                                sleep(1)
                                tft.ambient_temp_sensor()

                                if self.timer < 5:
                                    stepper.deinit()
                                    self.interrupter()
                                    return "incubation is done.\n"
                            else:
                                # Stepper will be stopped in 10 seconds
                                _ramp = ramp[idx+1:] if idx>len(ramp)/2 else ramp[idx-1::-1]
                                for _frequency in _ramp:
                                    sleep(round((10 / sum(_ramp)) * _frequency, 3))
                                break
            except Exception as e:
                for pin in [self.p_EN, self.p_BF, self.p_PH]:
                    pin.value(0)
                return e

    def sampling_thrd(self, direction=0, cycles=1, e=1.0, quiet_time=2.0, samples=3, acquisition_time=1, intervals=0.1, raw2avg=10, adc_read='Slow', pv=30):
        """Motor rotates clockwise for [revs]cycles;
        in each cycle rotates for 200/[samples] * 1.8 degrees;
        stops for [acquisition_time]seconds on each sample."""

        for thrd in _thread.list(False):
            if thrd[2] in ['gc_thrd', 'status_thrd']:
                _ = _thread.notify(thrd[0], _thread.EXIT)
                sleep(0.25)

        sleep(quiet_time)
        stepper = Pin(self.step_pin, Pin.OUT)
        self.collected_data = []
        if adc_read == 'Slow':
            sampler = DetectionModule(34, 25, pv)
        else:
            sampler = DetectionModule(39, 25, pv)
        self.interrupter()
        self.pwr.value(1)
        self.dir.value(direction if direction in [0, 1] else 0)

        while True:
            try:
                for _ in range(cycles):
                    for i in range(samples):
                        for _ in range(int(self.spr/samples)):
                            stepper.value(1)
                            sleep(self.delay)
                            stepper.value(0)
                            sleep(self.delay)

                        self.ejack.pull_down(1200, 0.001)
                        self.echem.applied_potential(e)

                        self.collected_data.append(('Sample {}:'.format(i+1), sampler.sampler(acquisition_time, intervals, raw2avg)))

                        self.echem.release()
                        self.ejack.lift_up(1200, 0.001)
                response = ({'header': 'sampling'})
                response.update({'body': self.collected_data})
                response.update({'notes': [samples, acquisition_time, intervals, raw2avg]})

                # self.echem.deinit()
                sampler.deinit()
                self.interrupter()

                with open('resp.txt', 'w') as resp:
                    resp.write(json.dumps(response))

                with open('resp.txt', 'r') as r:
                    for line in r:
                        SerialConnection().sr_sender(line)
                sleep(0.25)
                
                _ = _thread.start_new_thread('status_thrd', tft.status_thrd, ())
                sleep(0.1)
                # _ = _thread.start_new_thread('gc_thrd', MemSweep.gc_thrd, ())
                # sleep(0.1)
                return 'Done sending data.'

            except KeyboardInterrupt:
                print(RED + 'stepper: aborted!' + WHITE)
                self.interrupter()
                return
            except Exception as e:
                print(e)
                self.interrupter()
                return

    def interrupter(self, delay=0.01):
        """Motor rotates clockwise to finally be stopped by the opto-interrupter."""
        self.dir.value(0)
        self.pwr.value(1)
        stepper = Pin(self.step_pin, Pin.OUT)
        try:
            if self.intrptr.value():
                self.pwr.value(0)
                return
            while True:
                stepper.value(1)
                sleep(delay)
                stepper.value(0)
                if self.intrptr.value():
                    self.pwr.value(0)
                    break
            return
        except KeyboardInterrupt:
            self.pwr.value(0)
            return 'aborted!'
        except Exception as e:
            print(e)
            self.pwr.value(0)
            return 'shutting down.'

    def stpr_chk(self, delay=0.01, duration=10):
        """Motor rotates clockwise to finally be stopped by the opto-interrupter."""
        self.dir.value(0)
        self.pwr.value(1)
        stepper = Pin(self.step_pin, Pin.OUT)

        try:
            for _ in range(int(duration/delay)):
                stepper.value(1)
                sleep(delay)
                stepper.value(0)
            self.pwr.value(0)
            return
        except KeyboardInterrupt:
            self.pwr.value(0)
            return 'aborted!'
        except Exception as e:
            print(e)
            self.pwr.value(0)
            return 'shutting down.'
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

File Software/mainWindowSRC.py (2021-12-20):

import sys, os, time, json, serial, socket
from pyqtgraph.functions import FLOAT_REGEX
from PyQt5 import QtWidgets, QtTest, QtCore, QtGui
from PyQt5.QtCore import pyqtSlot, pyqtSignal, QSettings
import pyqtgraph as pg
import matplotlib.pyplot as plt
import numpy as np
import serial.tools.list_ports as lp
from array import array
import csv
import pandas as pd
import qdarkstyle, qdarkgraystyle
import threading
import traceback
import mainWindowGUI, WifiWindow, PreferencesWindow

__APPNAME__ = "LucidSens"
__VERSION__ = "1.01"

class WorkerSignals(QtCore.QObject):
    '''
    Defined Signals for the Worker thread:
    DONE: str -> resp['header']
    ERROR: tuple -> (exctype, value, traceback.format_exc())
    OUTPUT: dict -> response
    PROGRESS: int -> (progress in %)
    '''
    DONE = pyqtSignal(str)
    ERROR = pyqtSignal(tuple)
    OUTPUT = pyqtSignal(dict)
    PROGRESS = pyqtSignal(int)

class Worker(QtCore.QRunnable):
    ''' Worker thread '''
    def __init__(self, method, *args, **kwargs):
        super(Worker, self).__init__()
        self.method = method
        self.args = args
        self.kwargs = kwargs
        self.signals = WorkerSignals()
        self.kwargs['progress_callback'] = self.signals.PROGRESS

    @pyqtSlot()
    def run(self):
        '''Worker thread runner method'''
        try:
            output = self.method(*self.args, **self.kwargs)
            # print(output, type(output))
        except:
            traceback.print_exc()
            exctype, value = sys.exc_info()[:2]
            self.signals.ERROR.emit((exctype, value, traceback.format_exc()))
        else:
            self.signals.OUTPUT.emit(output) 
        finally:
            self.signals.DONE.emit(output['header'])

class Delegate(QtWidgets.QStyledItemDelegate):
    """Creates a deleagte for the Preferences options"""
    def editorEvent(self, event, model, option, index):
        value = QtWidgets.QStyledItemDelegate.editorEvent(self, event, model, option, index)        
        if value:
            if event.type() == QtCore.QEvent.MouseButtonRelease:
                if index.data(QtCore.Qt.CheckStateRole) == QtCore.Qt.Checked:
                    parent = index.parent()
                    for i in range(model.rowCount(parent)):
                        if i != index.row():
                            ix = parent.child(i, 0)
                            model.setData(ix, QtCore.Qt.Unchecked, QtCore.Qt.CheckStateRole)
        return value

class Preferences(QtWidgets.QMainWindow, PreferencesWindow.Ui_Preferences):
    """Preferences Window"""
    def __init__(self):
        super().__init__()
        self.setupUi(self)
        self.treeWidget.setHeaderHidden(True)
        self.treeWidget.setItemDelegate(Delegate())
        self.treeWidget.expandAll()
        self.settings = QSettings('Theme')
        self._theme = self.settings.value('Theme')
        if self._theme:
            self.treeWidget.setCurrentItem(self.treeWidget.topLevelItem(0))
            model = self.treeWidget.model()
            index = self.treeWidget.currentIndex()
            if model.data(index) == 'Themes':
                index = self.treeWidget.currentIndex().child(0,0)
            parent_idx = index.parent()
            for i in range(model.rowCount(parent_idx)):
                idx = parent_idx.child(i, 0)
                if model.data(idx) == self._theme:
                    model.setData(idx, QtCore.Qt.Checked, QtCore.Qt.CheckStateRole)
                else:
                    pass

class WifiSettings(QtWidgets.QWidget, WifiWindow.Ui_WifiSettings):
    """Wifi Window"""
    def __init__(self):
        super().__init__()
        self.setupUi(self)

class Form(QtWidgets.QMainWindow, mainWindowGUI.Ui_MainWindow):
    """Main window"""
    def __init__(self, parent=None):
        super(Form, self).__init__(parent)

        self.content = ''
        self.current_file = ''
        # self.timer = QtCore.QTimer()
        self.threadpool = QtCore.QThreadPool()

        self.serial_connection = False
        self.wifi_connection = False
        # self.bt_connected = False

        self.setupUi(self)
        self.actionOpen.triggered.connect(self.open)
        self.actionNew.triggered.connect(self.new)
        self.actionSave_As.triggered.connect(self.save_as)
        self.actionSave.triggered.connect(self.save)
        self.actionStop.triggered.connect(self.stop)
        self.actionExit.triggered.connect(self.exit)
        self.actionAbout_Us.triggered.connect(self.about_us)
        self.actionHelp.triggered.connect(self.help)
        self.actionWifi.triggered.connect(self.wifi_panel) 
        self.RunButton.clicked.connect(self.run)
        self.TestButton.clicked.connect(self.run_test)
        self.actionConnection.triggered.connect(self.connection_status)
        self.actionPreferences.triggered.connect(self.preferences)
        
        self.graphicsView.clear()
        self.p0 = self.graphicsView.addPlot()
        self.p0.showAxis('right', show=True)
        self.p0.showAxis('top', show=True)
        self.p0.showGrid(x=True, y=True, alpha=1)
        
        self.textBrowser.append(self.pen(3, 'cyan') +  "Lucid" + "</font>" + self.pen(3, 'orange') + "Sens" + "</font>" + self.pen(2, 'white') + " (A device for electrochemiluminescence measurements)" + "</font>")
        self.textBrowser.append(self.pen(2, 'green') + "-"*50)
        self.textBrowser.append(self.pen(2, 'green') + f"Version {__VERSION__}")
        self.textBrowser.append(self.pen(2, 'green') +"Developed by M. Amin Haghighatbin")
        # self.textBrowser.append(self.pen(2, 'green') +"中国科学技术大学")
        # self.textBrowser.append(self.pen(2, 'green') +"University of Science and Technology of China (USTC)")
        self.textBrowser.append(self.pen(2, 'green') +"-"* 50)

        self.checkBox_SampMod.stateChanged.connect(self.sampling_mod_status)
        self.checkBox_IncubMod.stateChanged.connect(self.incubation_mod_status)
        self.checkBox_DataSmth.stateChanged.connect(self.data_processing_mod_status)
        
        # Incubation Mode
        self.lineEdit_IncubTime.editingFinished.connect(self.itm_chk)
        self.lineEdit_IncubTemp.editingFinished.connect(self.itp_chk)
        self.comboBox_BlowerStat.currentIndexChanged.connect(self.bf_chk)

        # Sampling Mode
        self.lineEdit_AppliedPotential.editingFinished.connect(self.pot_chk)
        self.lineEdit_SampQuietTime.editingFinished.connect(self.sqt_chk)
        self.lineEdit_NumbSamps.editingFinished.connect(self.sn_chk)
        self.lineEdit_SampTime.editingFinished.connect(self.st_chk)
        self.lineEdit_SampIntrvl.editingFinished.connect(self.csi_chk)
        self.lineEdit_Raw2Avrg.editingFinished.connect(self.r2avg_chk)
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

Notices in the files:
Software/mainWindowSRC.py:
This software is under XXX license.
